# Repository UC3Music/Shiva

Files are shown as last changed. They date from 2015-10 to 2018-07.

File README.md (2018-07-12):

Shiva
--------------------------
Up to 8 piezo sensors with MIDI out (standard and USB) to make an electronic drumset

<p align="center">
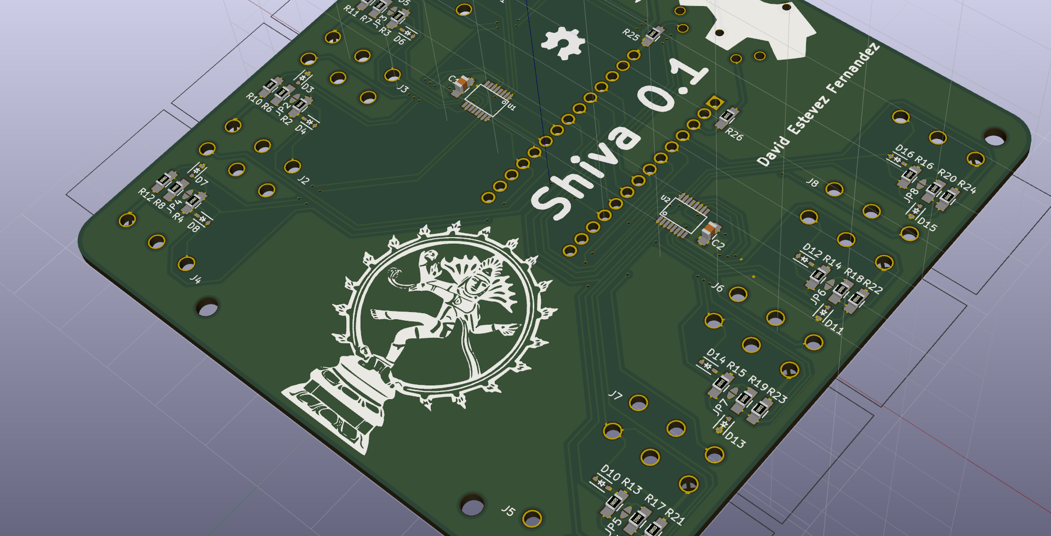
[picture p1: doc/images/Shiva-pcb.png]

</p>

## v1.0 Prototype
### Known bugs

[Known bugs](https://github.com/UC3Music/Shiva/issues?q=is%3Aissue+is%3Aopen+label%3Abug)

## v0.1 Prototype
### PCBs

<p align="center">
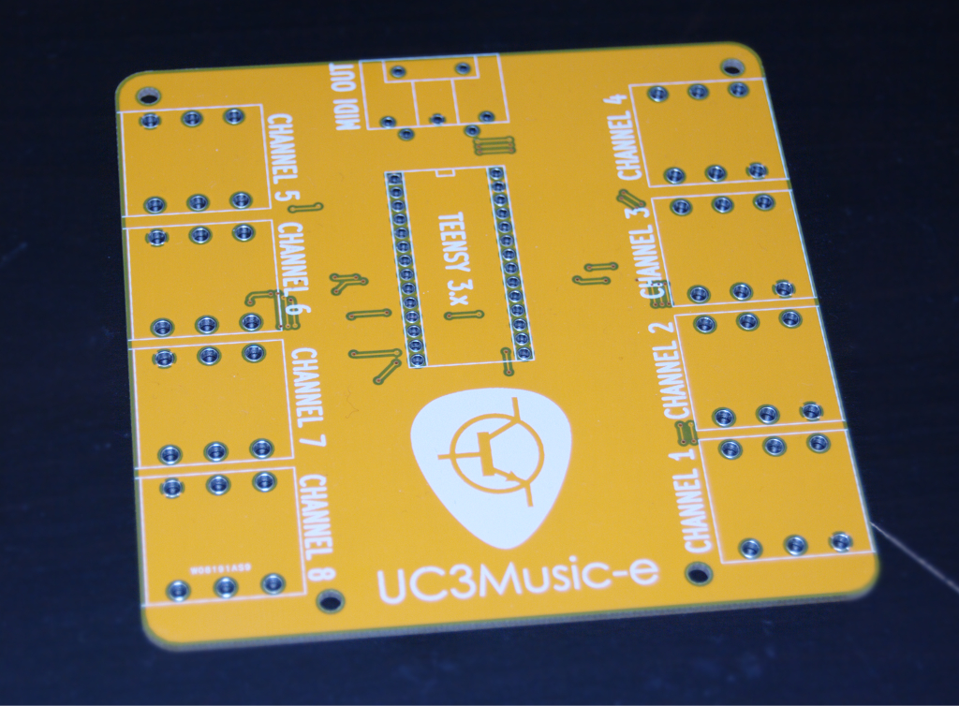
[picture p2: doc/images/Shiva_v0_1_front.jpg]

</p>
<p align="center">
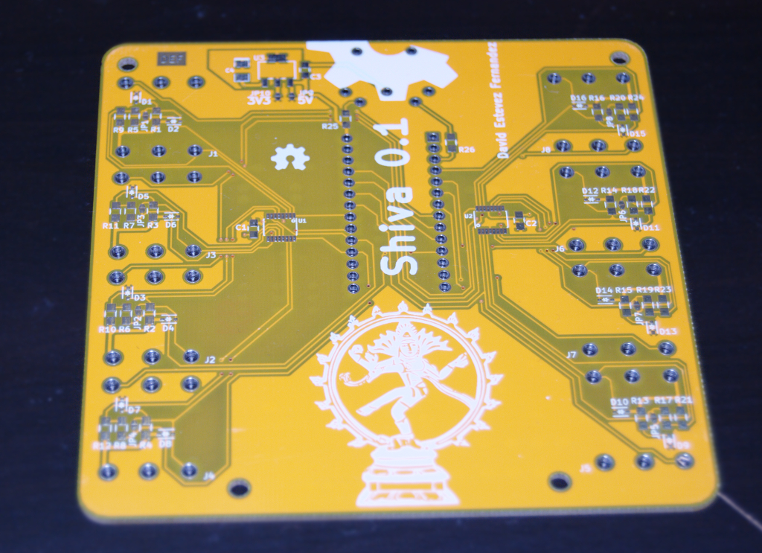
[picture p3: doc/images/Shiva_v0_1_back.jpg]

</p>

## Proof of concept

Proof of concept done with an Arduino Micro board (click on the images below to go to the videos):

MIDI Experiments with Arduino (http://www.youtube.com/watch?v=2-d8FWZnlz4)

MIDI Experiments with Arduino (2) (http://www.youtube.com/watch?v=U5sJlg9klXo)

# Acknowledgments

 * Inspired by KORG's [CLIPHIT](http://www.korg.com/us/products/drums/cliphit/)
 * Conditioning circuit for piezo sensors is based on [ScienceProg's circuit](http://www.scienceprog.com/thoughts-on-interfacing-piezo-vibration-sensor/)

# Credits
* Author: [David Estevez Fernandez](https://github.com/David-Estevez)

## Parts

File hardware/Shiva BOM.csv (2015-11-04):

Component | Amount | Reference | Seller | Unit Cost | Cost
Jack Female 6.35mm THD | 8 | 568-NYS219 | Mouser | 0.724 | 5.792
Diode Zener 3.3V SOD-323 | 16 | 863-MM3Z3V3T1G | Mouser | 0.127 | 2.032
Resistor 0603 220R | 2 | 71-CRCW0603-220-E3 | Mouser | 0.0091 | 0.0182
Regulator LD1117S33CTR | 1 | 511-LD1117S33C | Mouser | 0.462 | 0.462
Resistor 0805 ~320M | 8 | 667-ERJ-6GEYJ106V | Mouser | 0.081 | 0.648
Op-Amp LTC6242 | 2 | - | - |  | 0 | (samples)
Socket DIN 5 female THD | 1 | 502-57PC5F | Mouser | 2.33 | 2.33
R1 | 8 | 588-AS08J1002ET | Mouser | 0.054 | 0.432
R2 | 8 | 667-ERJ-6GEYJ203V | Mouser | 0.081 | 0.648
Capacitor 0805 ceramic 100nF | 3 | 80-C0805C104K3R | Mouser | 0.091 | 0.273
Capacitor 1206 polarized 10uF | 1 | 647-F931A106MAA | Mouser | 0.091 | 0.091
 |  |  |  | Total: | 12.7262

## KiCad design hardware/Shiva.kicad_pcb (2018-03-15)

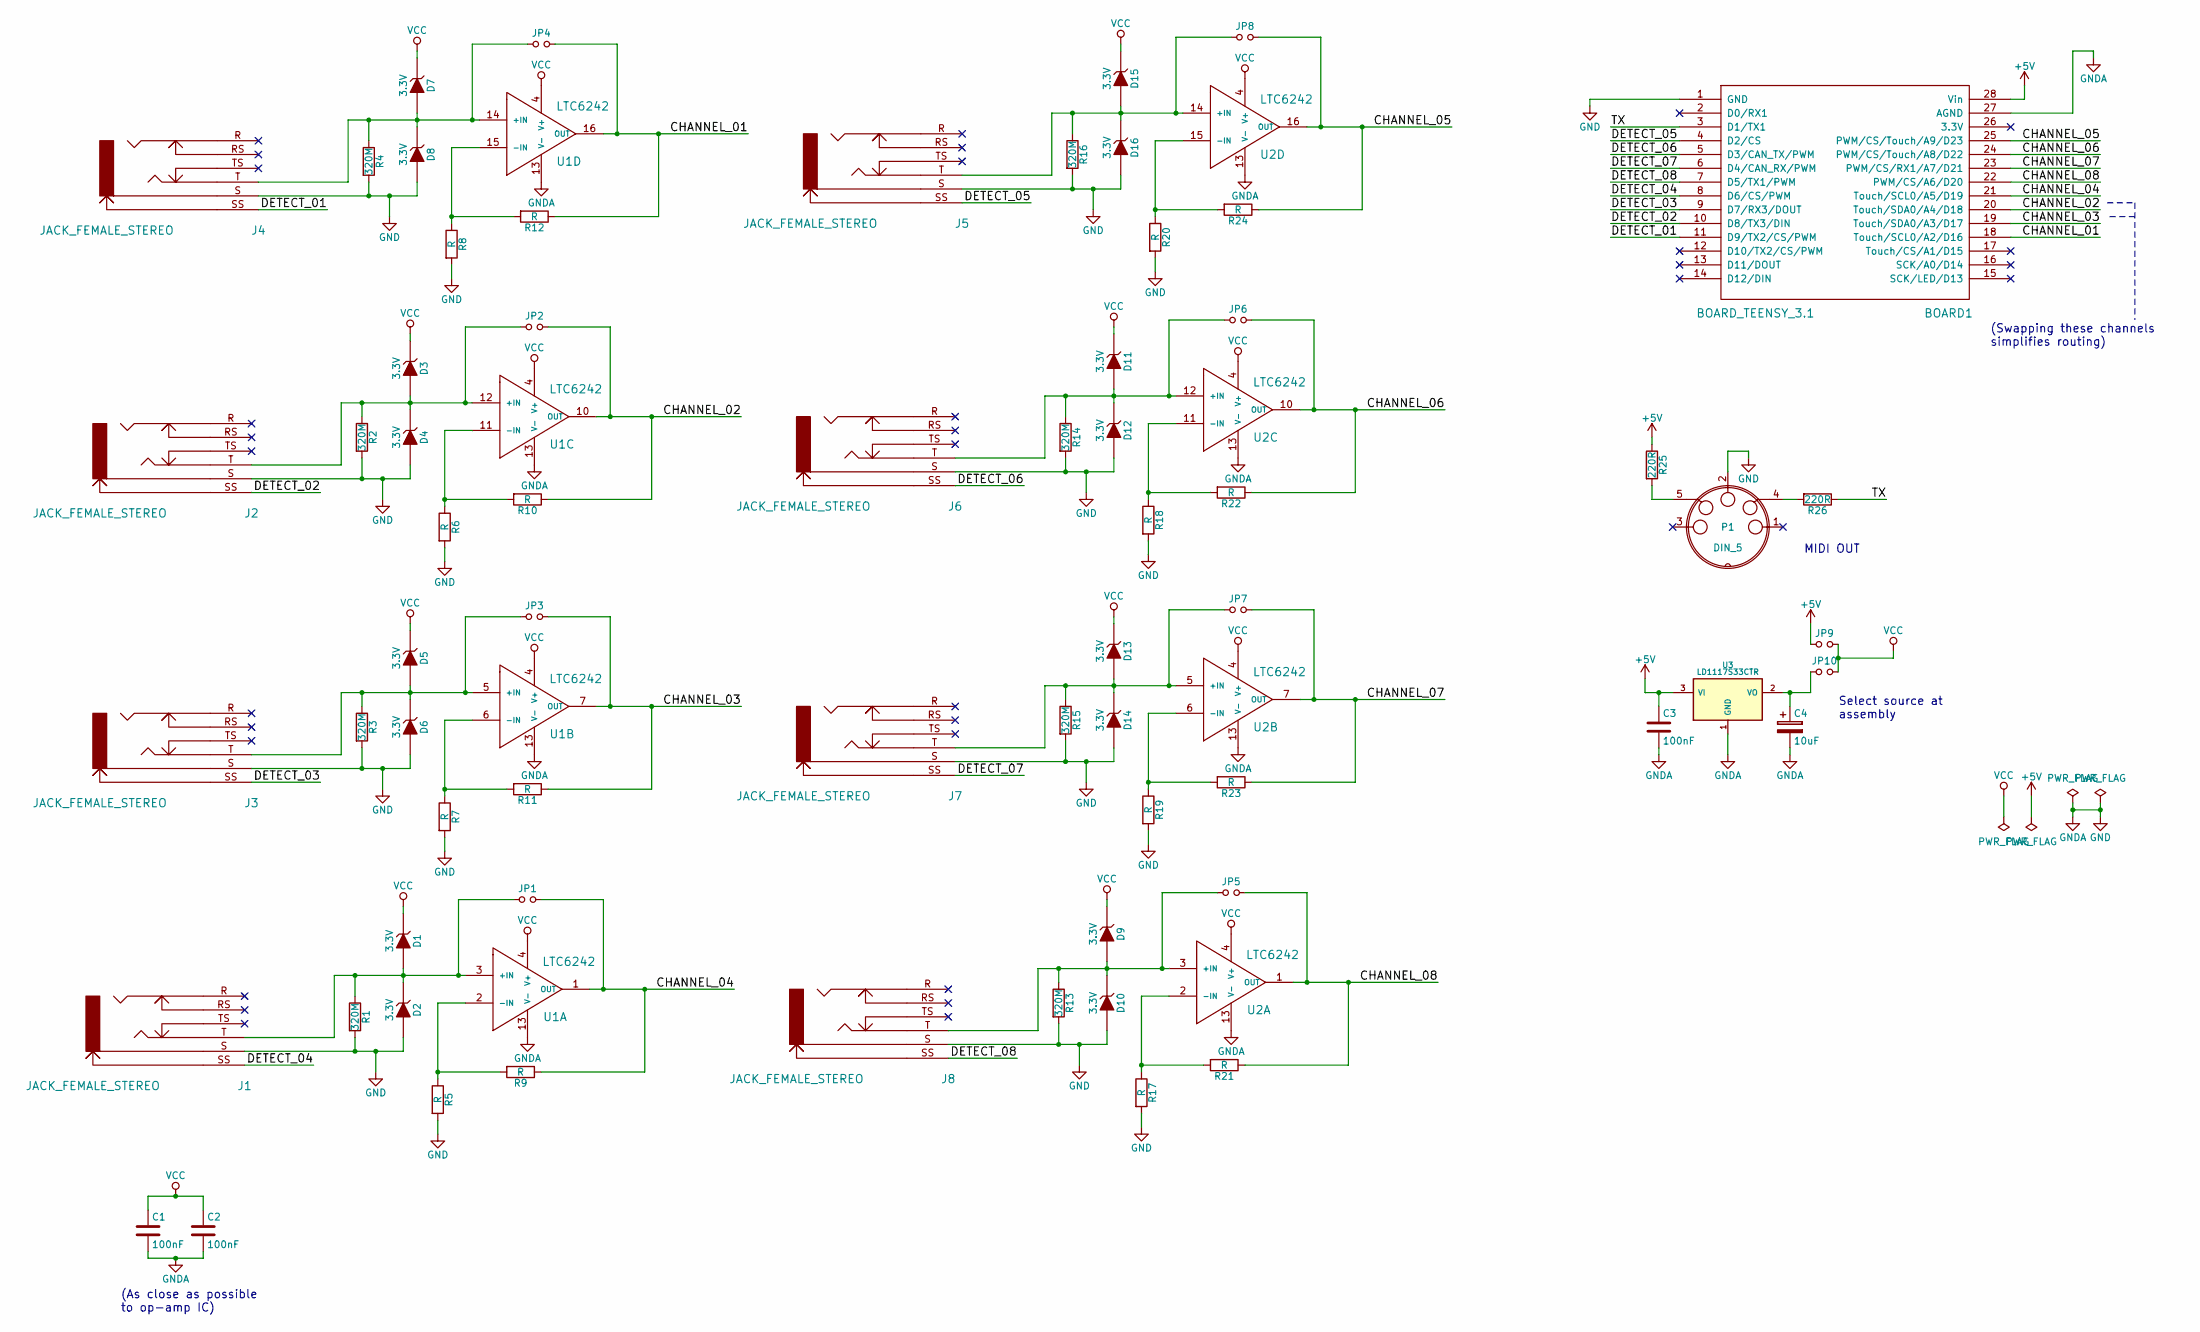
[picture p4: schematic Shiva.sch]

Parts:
BOARD1: BOARD_TEENSY_3.1; Board_Teensy_3_1
C1, C2, C3: 100nF; C_0805_HandSoldering
C4: 10uF; Package_1206_pol
D1, D2, D3, D4, D5, D6, D7, D8, D9, D10, D11, D12, D13, D14, D15, D16: 3.3V; D_SOD-323_HandSoldering
J1, J2, J3, J4, J5, J6, J7, J8: JACK_FEMALE_STEREO; CONN_Jack_Female_6.35mm_THD
JP1, JP2, JP3, JP4, JP5, JP6, JP7, JP8, JP9, JP10: Jumper_NO_Small; Miscellaneous_Solder_Jumper
P1: DIN_5; CONN_DIN5_Socket
R1, R2, R3, R4, R13, R14, R15, R16: 320M; R_0805_HandSoldering
R5, R6, R7, R8, R9, R10, R11, R12, R17, R18, R19, R20, R21, R22, R23, R24: R; R_0603_HandSoldering
R25, R26: 220R; R_0603_HandSoldering
U1, U2: LTC6242; Package_SSOP16
U3: LD1117S33CTR; Package_SOT-223-3

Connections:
+5V: BOARD1.28 (Vin), C3.1, JP9.1, R25.1, U3.3 (VI)
/CHANNEL_01: BOARD1.18 (Touch/SCL0/A2/D16), JP4.2, R12.1, U1.16 (OUT)
/CHANNEL_02: BOARD1.20 (Touch/SDA0/A4/D18), JP2.2, R10.1, U1.10 (OUT)
/CHANNEL_03: BOARD1.19 (Touch/SDA0/A3/D17), JP3.2, R11.1, U1.7 (OUT)
/CHANNEL_04: BOARD1.21 (Touch/SCL0/A5/D19), JP1.2, R9.1, U1.1 (OUT)
/CHANNEL_05: BOARD1.25 (PWM/CS/Touch/A9/D23), JP8.2, R24.1, U2.16 (OUT)
/CHANNEL_06: BOARD1.24 (PWM/CS/Touch/A8/D22), JP6.2, R22.1, U2.10 (OUT)
/CHANNEL_07: BOARD1.23 (PWM/CS/RX1/A7/D21), JP7.2, R23.1, U2.7 (OUT)
/CHANNEL_08: BOARD1.22 (PWM/CS/A6/D20), JP5.2, R21.1, U2.1 (OUT)
/DETECT_01: BOARD1.11 (D9/TX2/CS/PWM), J4.SS
/DETECT_02: BOARD1.10 (D8/TX3/DIN), J2.SS
/DETECT_03: BOARD1.9 (D7/RX3/DOUT), J3.SS
/DETECT_04: BOARD1.8 (D6/CS/PWM), J1.SS
/DETECT_05: BOARD1.4 (D2/CS), J5.SS
/DETECT_06: BOARD1.5 (D3/CAN_TX/PWM), J6.SS
/DETECT_07: BOARD1.6 (D4/CAN_RX/PWM), J7.SS
/DETECT_08: BOARD1.7 (D5/TX1/PWM), J8.SS
/TX: BOARD1.3 (D1/TX1), R26.1
GND: BOARD1.1 (GND), BOARD1.27 (AGND), C1.2, C2.2, C3.2, C4.2, D2.2 (A), D4.2 (A), D6.2 (A), D8.2 (A), D10.2 (A), D12.2 (A), D14.2 (A), D16.2 (A), J1.S, J2.S, J3.S, J4.S, J5.S, J6.S, J7.S, J8.S, P1.2, R1.2, R2.2, R3.2, R4.2, R5.2, R6.2, R7.2, R8.2, R13.2, R14.2, R15.2, R16.2, R17.2, R18.2, R19.2, R20.2, U1.13 (V-), U2.13 (V-), U3.1 (GND)
unnamed: C4.1, JP10.1, U3.2 (VO)
unnamed: D1.2 (A), D2.1 (K), J1.T, JP1.1, R1.1, U1.3 (+IN)
unnamed: D3.2 (A), D4.1 (K), J2.T, JP2.1, R2.1, U1.12 (+IN)
unnamed: D5.2 (A), D6.1 (K), J3.T, JP3.1, R3.1, U1.5 (+IN)
unnamed: D7.2 (A), D8.1 (K), J4.T, JP4.1, R4.1, U1.14 (+IN)
unnamed: D9.2 (A), D10.1 (K), J8.T, JP5.1, R13.1, U2.3 (+IN)
unnamed: D11.2 (A), D12.1 (K), J6.T, JP6.1, R14.1, U2.12 (+IN)
unnamed: D13.2 (A), D14.1 (K), J7.T, JP7.1, R15.1, U2.5 (+IN)
unnamed: D15.2 (A), D16.1 (K), J5.T, JP8.1, R16.1, U2.14 (+IN)
unnamed: P1.4, R26.2
unnamed: P1.5, R25.2
unnamed: R5.1, R9.2, U1.2 (-IN)
unnamed: R6.1, R10.2, U1.11 (-IN)
unnamed: R7.1, R11.2, U1.6 (-IN)
unnamed: R8.1, R12.2, U1.15 (-IN)
unnamed: R17.1, R21.2, U2.2 (-IN)
unnamed: R18.1, R22.2, U2.11 (-IN)
unnamed: R19.1, R23.2, U2.6 (-IN)
unnamed: R20.1, R24.2, U2.15 (-IN)
VCC: C1.1, C2.1, D1.1 (K), D3.1 (K), D5.1 (K), D7.1 (K), D9.1 (K), D11.1 (K), D13.1 (K), D15.1 (K), JP9.2, JP10.2, U1.4 (V+), U2.4 (V+)

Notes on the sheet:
MIDI OUT
Select source at assembly
(As close as possible to op-amp IC)
(Swapping these channels simplifies routing)

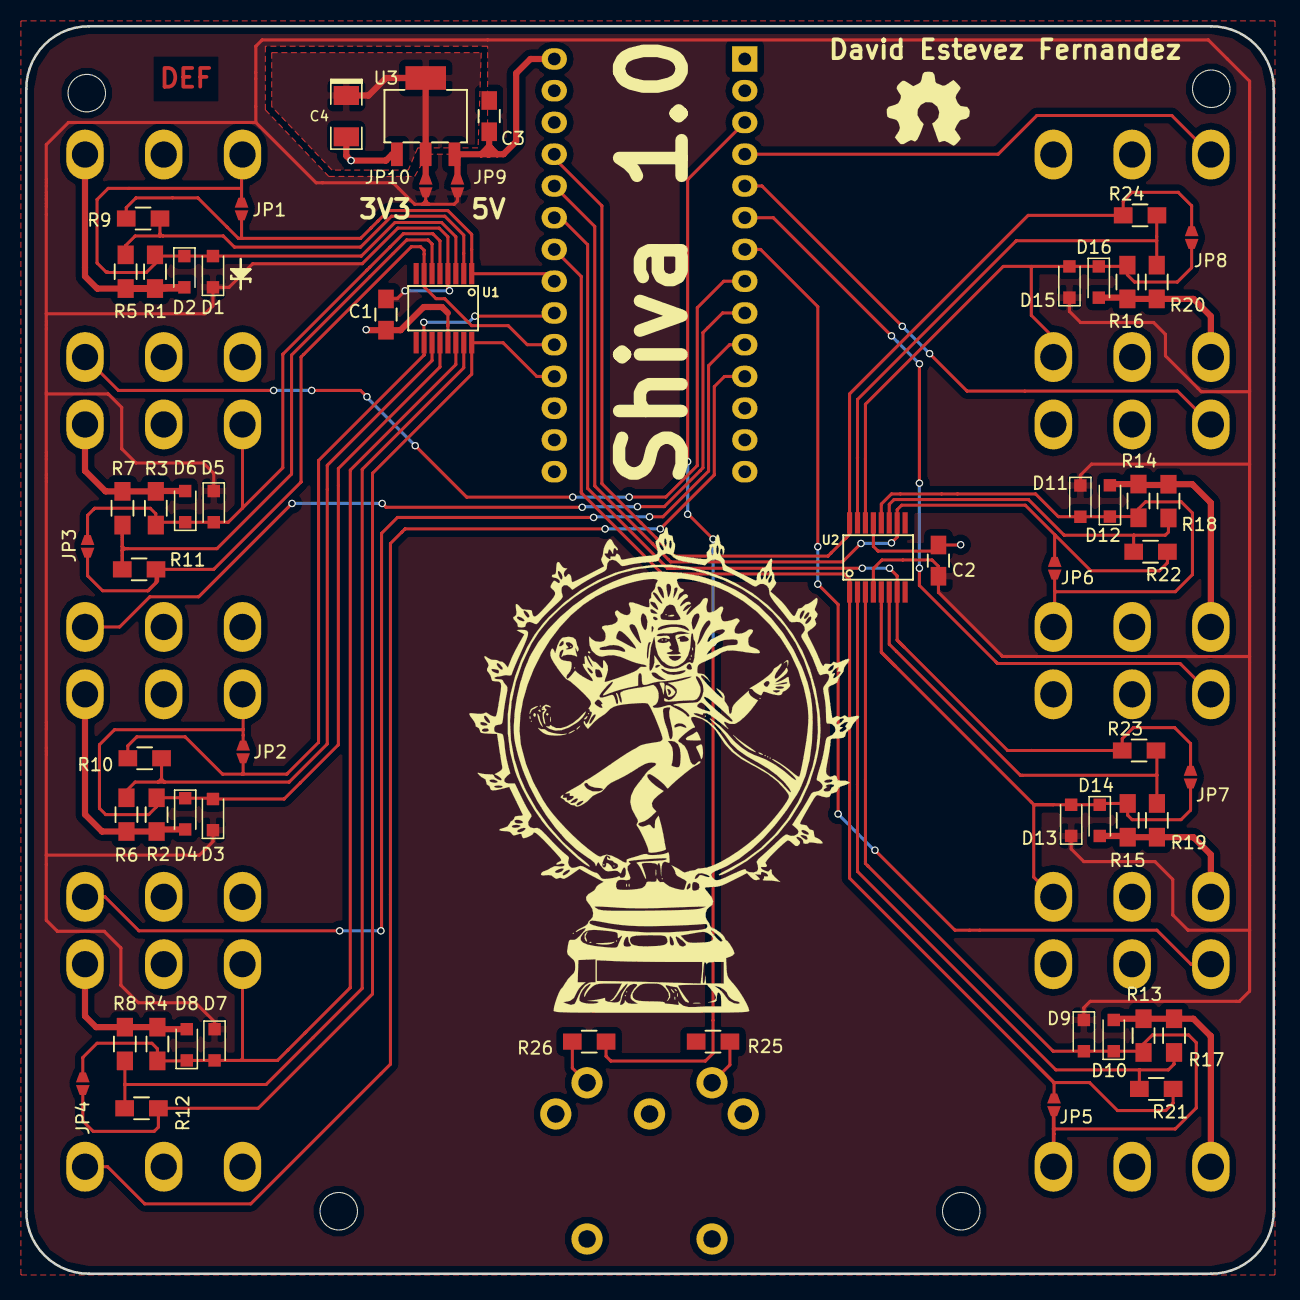
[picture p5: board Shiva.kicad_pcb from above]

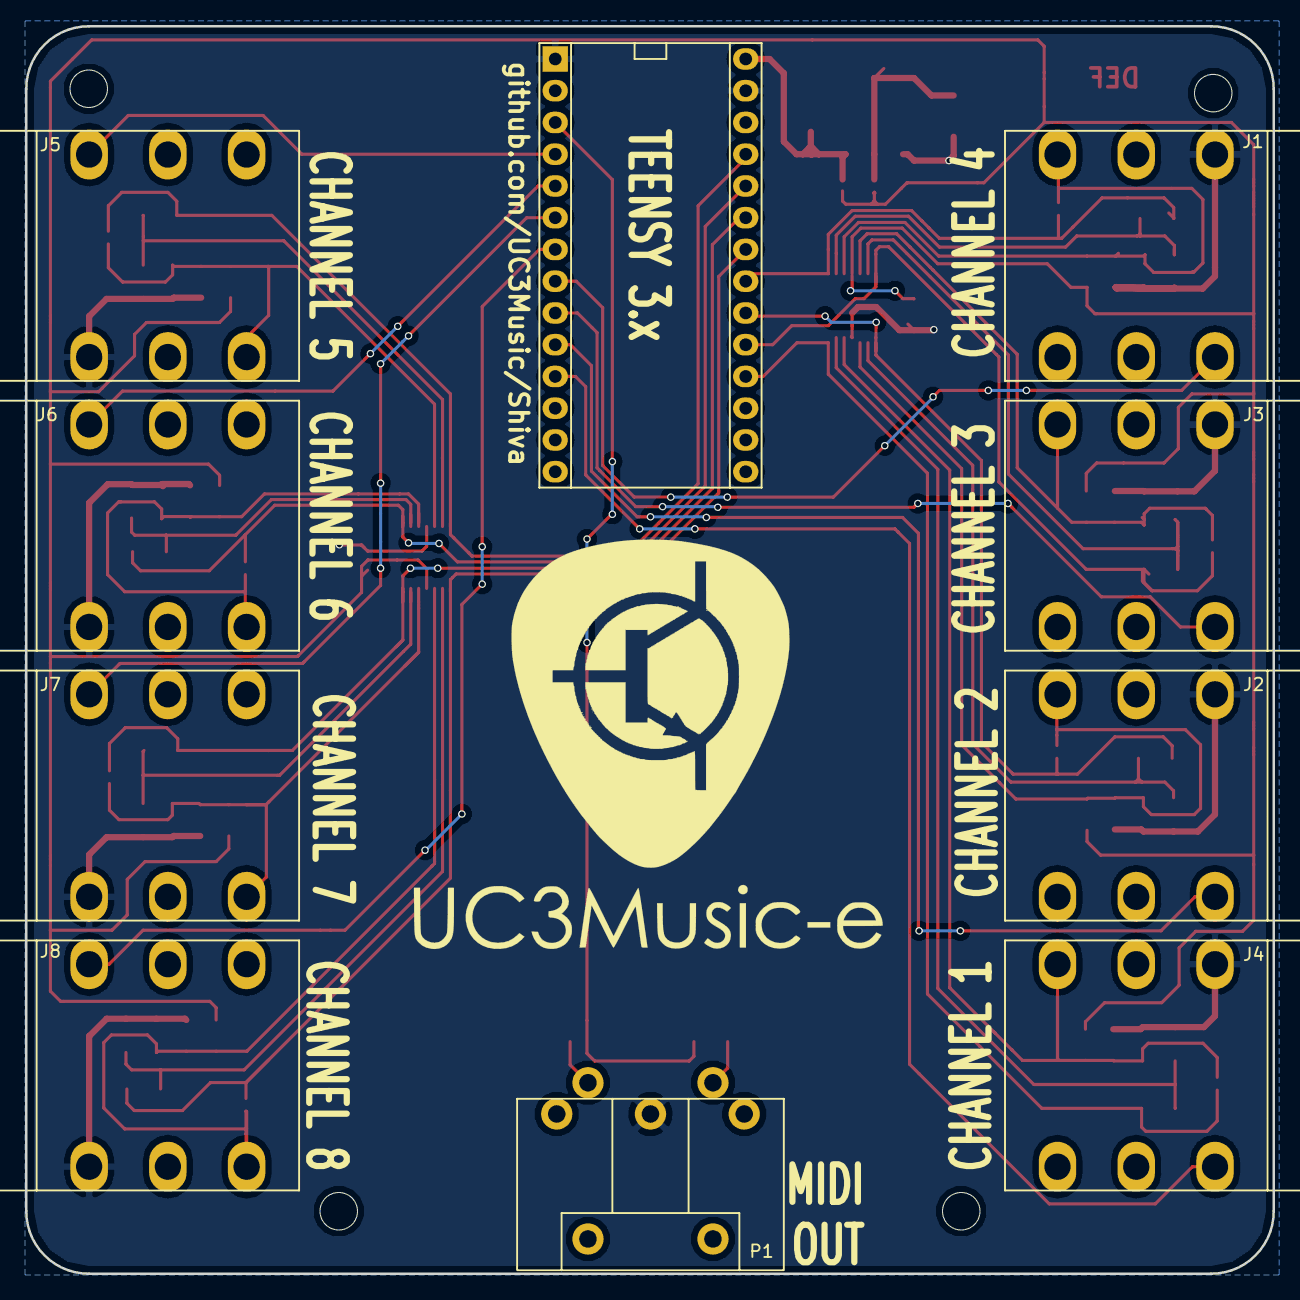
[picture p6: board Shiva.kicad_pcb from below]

Board: 2 copper layers, 99.8 x 99.8 mm, 73 parts (10 on the bottom side), 39 nets.

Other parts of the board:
Mechanical_drill_3mm, Mechanical_drill_3mm#2, Mechanical_drill_3mm#3, Mechanical_drill_3mm#4: Mechanical_Drill_3mm

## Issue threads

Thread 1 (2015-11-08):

Prototype v0.1 bugs

David-Estevez, 2015-11-08:
Things to correct in version 1.0 / 0.2:
- [x] Pads for through-hole components are too thin.
- [x] Reposition Teensy board (USB and MIDI connector collide).
- [x] Jack connectors are placed in the wrong side of the board.

Critical:
- [x] Silkscreens for R12 and R8 are swapped (reported by @JorFru )

David-Estevez, 2018-02-23:
* [ ] Op-amp inputs are swapped for all channels (reported by @SerjSanchez)

David-Estevez, 2018-02-23:
@SerjSanchez was right, the + and - inputs of the op-amps were swapped, and therefore it was working in an unstable configuration (due to positive feedback).

Changing this in the PCB (+other hacks) makes it work properly, although it might need a gain higher than 1. But the gain could be adjusted with the correct circuit by adding resistors.

David-Estevez, 2018-03-04:
Fixed flipped jacks, swapped op-amp channels, thin pads, swapped silkscreen ids (f301a64)

David-Estevez, 2018-03-07:
Components placement fixed at 8a9add0

JorFru, 2018-03-16:
Pick logo and UC3Music name logo are outdated versions.
Updated versions will be available soon [here](https://github.com/UC3Music/uc3music-logos/tree/master/logos)

David-Estevez, 2018-03-16:
Issue #13 already covers that issue

Closed 2018-03-16.

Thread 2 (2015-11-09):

Add URL to Silkscreen

David-Estevez, 2015-11-09:
Add URL of this repo to the PCB Silkcreen

David-Estevez, 2018-03-04:
Fixed at 55aef68

Closed 2018-03-04.

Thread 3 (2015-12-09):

Pads for SMD components too small

David-Estevez, 2015-12-09:
Current pads are not suitable for hand-soldering

David-Estevez, 2018-03-04:
Resistors, caps and regulator are ok, must change:

* [ ] Diodes
* [ ] Op-amps

David-Estevez, 2018-03-04:
Fixed at 651d34b

Closed 2018-03-04.

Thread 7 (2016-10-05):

Persistent changes in Shiva parameters

David-Estevez, 2016-10-05:
Current configuration changes through the Shiva software are not stored, and the configuration goes back to the default one when power is disconnected (or MCU is reset).

Add a 'commit' command to persistently store values in EEPROM.

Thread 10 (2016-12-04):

Weird behavior in some channels

David-Estevez, 2016-12-04:
Channels 1 and 4 of the v0.1 have a weird behavior.

When the jack contacts are separated (e.g. the piezo jack is inserted), the contacts voltage becomes VCC (which is weird).

@JorFru is currently in charge of inspecting the PCB in order to check that everything is OK (which obviously it is not)

David-Estevez, 2018-02-23:
Channels 1 and 4 where assembled in a different way than 2 and 3 and therefore the behavior was different. Other than that, the problems described in this issue are due to the hacks performed on the board, and will be addressed in #1

Closing issue as invalid.

Closed 2018-02-23.

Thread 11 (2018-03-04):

Reroute PCB

David-Estevez, 2018-03-04:
After all the component changes and connection fixes the PCB must be rerouted almost completely.

Progress tracking:

* [x] Channel 1
* [x] Channel 2
* [x] Channel 3
* [x] Channel 4
* [x] Channel 5
* [x] Channel 6
* [x] Channel 7
* [x] Channel 8
* [x] Jack detects
* [x] Other routing left

David-Estevez, 2018-03-16:
Everything routed at 68fd877d995b6a88ff0451302a6bc5c22e8365f1

Closed 2018-03-16.

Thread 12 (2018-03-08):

Broken layout after rerouting channel 4

David-Estevez, 2018-03-08:
After rerouting channel 4, some hidden elements were moved by mistake, breaking the layout (silkscreen and some zone boundaries).

David-Estevez, 2018-03-14:
Fixed in c07caa1

(As simple as looking to the PCB code in diff and restoring the proper values)

Closed 2018-03-14.

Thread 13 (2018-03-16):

Update logo(s) in PCB

David-Estevez, 2018-03-16:
Blocked by https://github.com/UC3Music/uc3music-logos/issues/1

David-Estevez, 2018-03-24:
As I added new features to the board, there was no space left for the text logo, so now all logos in the board are updated.

Closed 2018-03-24.

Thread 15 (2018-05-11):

Assemble (and verify) Shiva 1.0

David-Estevez, 2018-05-11:
* [x] Assemble
* [x] Verify
* [x] Document errors (if present)

David-Estevez, 2018-06-13:
The PCBs and components arrived and I assembled most of a single prototype:

* All components except for one op-amp chip and 6 jacks were assembled.
* That means we can have up to 4 channels active, from which 2 have a jack to connect the sensor.

Most of the functionality was tested, finding that due to the internal resistance of the zener diodes, the input of the op-amp has an offset of VCC/2. This issue will be tracked in the following issue: #16

Apart from that, the only remaining thing it to develop the firmware functionality, more precisely:

* Detect hits: #17
* Detect when a sensor is used using digital inputs: #18
* Use the in-board joystick to select a channel and modify its sound without a PC: #19
* Send MIDI notes out of the MIDI OUT connector: #20

With all the found issues / new features already tracked by  other issues, this one can be closed.

Closed 2018-06-13.

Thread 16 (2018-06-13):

Sensor input has an offset

David-Estevez, 2018-06-13:
Due to the internal resistance of the zener diodes, the input of the op-amp has an offset of VCC/2.

Possible solutions: add a high-pass filter to filter out the offset.

David-Estevez, 2018-08-23:
I tried adding a capacitor to make a high-pass filter, but it didn't remove the offset.

After that, I tested the solution proposed by @SerjSanchez: removing the zener diodes to remove the offset. In principle this shouldn't damage the op-amp, since the voltage spikes that it may receive won't carry much current, so it (hopefully) shouldn't break.

Without the zener diodes there is no offset, so I'm closing this issue as fixed.

Closed 2018-08-23.

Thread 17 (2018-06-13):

Hit detection

David-Estevez, 2018-06-13:
Enable hit detection with current sensor input (VCC/2 offset -> #16 ).

David-Estevez, 2018-08-23:
Now that #16 has been solved, this issue can be simply solved by adjusting the thresholds.

Nevertheless, I have observed that the sensor detection (checking wether the piezo is present or not) affects the hit detection, as the microcontroller is busy checking for too long, and some hits are not detected if they are synced with the checking. This second part requires further testing.

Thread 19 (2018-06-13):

Channel properties selection without external PC

David-Estevez, 2018-06-13:
Use the in-board joystick to select a channel and modify its sound without a PC.

David-Estevez, 2018-08-23:
Fixed in 4a43160

Closed 2018-08-23.

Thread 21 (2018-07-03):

MIDI connector connections are incorrect

David-Estevez, 2018-07-03:
Currently, +5V is connected to pin 5 and TX is connected to pin 4:
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

However, it seems that the correct wiring is the following one:
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

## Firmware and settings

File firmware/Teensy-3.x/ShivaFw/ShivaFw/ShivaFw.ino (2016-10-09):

/*  Shiva
 *  -------------------------------------
 *  Electronic diy midi drumkit
 *
 *  Author: David Estevez Fernandez (DEF)
 *    https://github.com/David-Estevez
 *
 *  Shiva is a UC3Music project:
 *    https://github.com/UC3Music/Shiva
 *
 */

#include <Arduino.h>
#include <MIDI.h>

//-- Constants
#define N_CHANNELS 8
static const uint8_t input_pins[N_CHANNELS] = {A2, A3, A4, A5, A9, A8, A7, A6};
static const uint8_t channel_detect[N_CHANNELS] = {9, 8, 7, 6, 2, 3, 4, 5};
#define BAUD_RATE 9600

//-- Serial stuff
String buffer = "";
bool incoming_cmd = false;

void setup() {
  Serial.begin(BAUD_RATE);
  Serial.println("Shiva by UC3Music");

}

void loop()
{
  //-- Variables
  static uint16_t sensor_values[N_CHANNELS] = {0, 0, 0, 0, 0, 0, 0, 0};
  static uint16_t trigger_thresholds[N_CHANNELS] = {100, 100, 100, 100, 100, 100, 100, 100};
  static uint16_t off_thresholds[N_CHANNELS] = {50, 50, 50, 50, 50, 50, 50, 50};
  static uint8_t states[N_CHANNELS] = {0, 0, 0, 0, 0, 0, 0, 0};
  static uint8_t channel_enabled[N_CHANNELS] = {1, 1, 0, 0, 0, 0, 0};
  static uint8_t notes[N_CHANNELS] = {49, 49, 49, 49, 49, 49, 49, 49};
  static uint8_t verbose = false;


  //-- Read analog inputs for active channels
  for (uint8_t i = 0; i < N_CHANNELS; i++)
    if (channel_enabled[i])
    {
      sensor_values[i] = analogRead(input_pins[i]);
      if (verbose)
        Serial.println("S0C"+String(i)+"V"+String(sensor_values[i]));
    }

  //-- Manage state transitions for all channels
  for (uint8_t i = 0; i < N_CHANNELS; i++)
  {
    if (states[i] == 0 && sensor_values[i] > trigger_thresholds[i])
    {
      //-- Transition to state "ON" and send on note
      states[i] = 1;
      usbMIDI.sendNoteOn(notes[i], 64, 9);   // middle C, normal velocity, channel 9
      usbMIDI.send_now();
    }
    else if (states[i] == 1 && sensor_values[i] < off_thresholds[i])
    {
      //-- Transition to state "OFF" and send off note
      states[i] = 0;
      usbMIDI.sendNoteOff(notes[i], 64, 9);  //  middle C, normal velocity, channel 9
      usbMIDI.send_now();
    }
  }

  //-- MIDI Controllers should discard incoming MIDI messages
  while (usbMIDI.read()) {
  }

  //-- Take care of serial commands
  //-- Available commands:
  //-- S0 -> Enable verbose mode
  //-- S1 -> Disable verbose mode
  //-- S2CxVy -> Edit note y in channel x
  //-- S3CxVy -> Edit upper threshold (trigger) y in channel x
  //-- S4CxVy -> Edit lower threshold (off) y in channel x
  //-- S5Cx -> Query current note for channel x
  //-- S6Cx -> Query current upper threshold (trigger) y in channel x
  //-- S7Cx -> Query current lower threshold (off) y in channel x
  //-- S8Cx -> Query channel status (enabled/disabled)
  if (incoming_cmd)
  {
    //-- Parse command
    if (buffer[0]=='S')
    {
      if (buffer[1]=='0')
      {
        //-- Enable verbose mode
        verbose = true;
        Serial.println("Ok");
      }
      else if (buffer[1]=='1')
      {
        //-- Disable verbose mode
        verbose = false;
        Serial.println("Ok");
      }
      else if (buffer[1]=='2')
      {
        //-- Edit note per channel
        uint8_t channel_start = buffer.indexOf('C', 1);
        uint8_t value_start = buffer.indexOf('V', channel_start);
        uint8_t channel = buffer.substring(channel_start+1, value_start).toInt();
        uint8_t value = buffer.substring(value_start+1).toInt();
        if (channel < N_CHANNELS)
          notes[channel] = value;
        Serial.println("Ok");
      }
      else if (buffer[1]=='3')
      {
        //-- Edit upper threshold (trigger) per channel
        uint8_t channel_start = buffer.indexOf('C', 1);
        uint8_t value_start = buffer.indexOf('V', channel_start);
        uint8_t channel = buffer.substring(channel_start+1, value_start).toInt();
        uint8_t value = buffer.substring(value_start+1).toInt();
        if (channel < N_CHANNELS)
          trigger_thresholds[channel] = value;
        Serial.println("Ok");
      }
      else if (buffer[1]=='4')
      {
        //-- Edit lower threshold (off) per channel
        uint8_t channel_start = buffer.indexOf('C', 1);
        uint8_t value_start = buffer.indexOf('V', channel_start);
        uint8_t channel = buffer.substring(channel_start+1, value_start).toInt();
        uint8_t value = buffer.substring(value_start+1).toInt();
        if (channel < N_CHANNELS)
          off_thresholds[channel] = value;
        Serial.println("Ok");
      }
      else if (buffer[1]=='5')
      {
        //-- Query current note for channel x
        uint8_t channel = buffer.substring(3).toInt();
        if (channel < N_CHANNELS)
          Serial.println("S5C"+String(channel)+"V"+String(notes[channel]));
      }
      else if (buffer[1]=='6')
      {
        //-- Query current upper threshold (trigger) for channel x
        uint8_t channel = buffer.substring(3).toInt();
        if (channel < N_CHANNELS)
          Serial.println("S6C"+String(channel)+"V"+String(trigger_thresholds[channel]));
      }
      else if (buffer[1]=='7')
      {
        //-- Query current upper threshold (trigger) for channel x
        uint8_t channel = buffer.substring(3).toInt();
        if (channel < N_CHANNELS)
          Serial.println("S7C"+String(channel)+"V"+String(off_thresholds[channel]));
      }
      else if (buffer[1]=='8')
      {
        //-- Query status (enabled/disabled) for channel x
        uint8_t channel = buffer.substring(3).toInt();
        if (channel < N_CHANNELS)
          Serial.println("S8C"+String(channel)+"V"+String(channel_enabled[channel]));
      }

    }

    //-- Erase buffer
    incoming_cmd = false;
    buffer = "";

  }
  //-- Short delay to let ADC settle after the last reading
  delay(2);
}


//-- Reads the incoming chars and stores them in the buffer
void serialEvent()
{
  while (Serial.available())
  {
    char inChar = (char)Serial.read();
    buffer += inChar;
    if (inChar == '\n')
      incoming_cmd = true;
  }
}

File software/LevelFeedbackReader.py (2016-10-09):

"""
    LevelFeedbackReader
    -----------------------------------------------------
    Class to read the information sent by Shiva in verbose mode (S0)
    Listeners can be added, and they will be notified when new information arrives
"""

import serial
import serial.threaded
import time

class LevelFeedbackReaderListener(object):
    """
    Objects of this class are notified of incoming data when added to this class
    """
    def notify(self, command, channel, value):
        raise NotImplementedError

class LevelFeedbackReader(serial.threaded.LineReader):
    """
    Reads the output of the command S0 (level feedback) using a dedicated thread
    """

    def __init__(self):
        super().__init__()
        self.listeners = []

    def connection_made(self, transport):
        """
        Callback called when the LineReader is started. Sends to Shiva the command
        to enter verbose mode (S0)
        """
        try:
            transport.write(bytes("S0\n", "UTF-8"))
        except Exception as e:
            print(e)

    def handle_line(self, data):
        """
        Callback called when a new line arrives from Shiva. When the command received
        is a feedback command, it notifies the listeners.
        """
        command, channel, value = self.parse_response(data)
        if command is not None:
            for listener in self.listeners:
                listener.notify(command, channel, value)

    def connection_lost(self, exc):
        print("Connection lost!", exc)

    @staticmethod
    def parse_response(response):
        """
        Parses a received line to extract the command that sent the information, and the
        channel and value of the sender command.
        :return: Three items: command id, channel id and value (all None if the data was invalid)
        """
        print(response)
        s = response.find('S')
        c = response[s+1:].find('C') + s+1
        v = response[c+1:].find('V') + c+1

        try:
            return int(response[s+1:c]), int(response[c+1:v]), int(response[v+1:])
        except ValueError:
            return None, None, None

    def add_listener(self, listener):
        if isinstance(listener, LevelFeedbackReaderListener):
            self.listeners.append(listener)

    def __call__(self, *args, **kwargs):
        """
        With this method, the LevelFeedbackReader becomes a protocol_factory, required
        to create a ReaderThread.
        :return: A reference to this object
        """
        return self

class BasicLevelFeedbackReaderListener(LevelFeedbackReaderListener):
    """
    Very simple listener that dumps received info to stdout
    """
    def notify(self, command, channel, value):
        print("{} {} {}".format(command, channel, value))

if __name__ == '__main__':
    ser = serial.Serial("/dev/ttyACM0", 9600)
    l = BasicLevelFeedbackReaderListener()
    line_reader = LevelFeedbackReader()
    line_reader.add_listener(l)

    ser_thread = serial.threaded.ReaderThread(ser, line_reader)
    ser_thread.start()
    time.sleep(5)
    ser_thread.stop()
    ser.close()

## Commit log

2015-10-16 Start designing input conditioning circuit
    [Shiva.sch]
2015-10-18 Add 8 input channels, Teensy, start MIDI interface
    [Shiva.sch]
2015-10-19 Add MIDI and regulator
    [Shiva.sch]
2015-10-19 Add some cmp assignments
    [Shiva.sch]
2015-10-20 Assign SSOP16 footprint
    [Shiva.sch]
2015-10-20 Assign 1206 pol to footprints
    [Shiva.sch]
2015-10-22 Preliminary routing
    [Shiva.kicad_pcb, Shiva.sch]
2015-10-22 Add logos, copper front plane
    [Shiva.kicad_pcb]
2015-10-23 Add drills and heatsinking
    [Shiva.kicad_pcb]
2015-10-23 Fix bug with midi tx. Finish silkscreen
    [Shiva.kicad_pcb, Shiva.sch]
2015-10-23 Modify silkscreen
    [Shiva.kicad_pcb]
2015-10-27 Fixed solder jumpers
    [Shiva.kicad_pcb]
2015-10-27 Generate GERBER files
    [Shiva.DRL, Shiva.GBL, Shiva.GBO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]
2015-10-30 Move hardware files to hardware folder
    [Shiva.DRL, Shiva.GBL, Shiva.GBO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]
2015-10-30 Add Arduino test MIDI firmware
2015-11-04 Add BOM file
    [Shiva BOM.csv]
2015-11-07 Add pictures of prototype
2015-11-07 Add PCB images to README
2015-12-10 Firmware for hardware testing of Shiva prototype
2016-10-01 Add support to get current status in Shiva firmware
2016-10-01 Add support to get current channel status in Shiva firmware
2016-10-06 Add test code to implement threaded reader of serial port
2016-10-08 Fix small bugs in feedback mechanism
    [Shiva.py]
2016-10-09 Fix signals to work on all channels (feedback enabled on all channels)
    [ShivaGUI.py]
2018-03-04 Fix swapped op-amp inputs
    [Shiva.sch]
2018-03-04 Fix jacks, thin pads, swapped silkscreen
    [Shiva.kicad_pcb]
2018-03-04 Add repo url
    [Shiva.kicad_pcb]
2018-03-04 Fix SMD footprints too small
    [Shiva.kicad_pcb, Shiva.sch]
2018-03-07 Change placement of required components
    [Shiva.kicad_pcb]
2018-03-08 Reroute channel 4
    [Shiva.kicad_pcb]
2018-03-13 Route channel 3
    [Shiva.kicad_pcb, Shiva.sch]
2018-03-13 Route channel 2
    [Shiva.kicad_pcb]
2018-03-14 Document channel swap in schematic
    [Shiva.sch]
2018-03-14 Restore old zones (fixes #12)
    [Shiva.kicad_pcb]
2018-03-15 Route channel 1
    [Shiva.kicad_pcb]
2018-03-15 Route channel 5, swap channels to simplify op-amp routing
    [Shiva.kicad_pcb, Shiva.sch]
2018-03-15 Route channel 6
    [Shiva.kicad_pcb]
2018-03-15 Route channel 7
    [Shiva.kicad_pcb]
2018-03-15 Route channel 8
    [Shiva.kicad_pcb]
2018-03-15 Fill zones, connect remaining stuff, beautify tracks
    [Shiva.kicad_pcb]
